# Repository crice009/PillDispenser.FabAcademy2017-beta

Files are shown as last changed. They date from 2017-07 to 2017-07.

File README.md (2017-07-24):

#Pill Dispenser (working title: Novelda)
Fab Academy2017 --beta

These files build a device that will manage pills medications for someone who needs to take them on a schedule. Ideally, this machine will dispense pills and make simple efforts to through sensors and alerts (local and internet based) to avoid too much or too little medication being taken at any time. Perhaps even with medication compliance information that could be useful for better understanding the user’s behavior. My hope was to create a valuable data stream, where there was none previously. 

To give this a more personal explanation: My grandmother recently passed of Alzheimer’s disease. My family regularly worried if she was taking her medications on schedule (as it was difficult or impossible for her to remember on her own. A device like this could manage that all for her. If everything worked perfectly, a family member could place the bottle of pills in the machine and then let it run in Grandma’s home on the kitchen counter. The machine would then dispense the pills on a schedule, but actively manage so they don’t get backlogged. An alarm would help Grandma remember when it was time to take the pills. Furthermore, an internet app could track her medication compliance, and email a family member to give Grandma a call if she seems to be getting off schedule. [This is a pie-in-the-sky dream, but the project is close to having all of those features integrated as of July 2017.] The working title given above could be a simplified name for a theoretical commercial device. It is also my own beloved grandmother’s name. 

<a href='https://youtu.be/coTj5rTIzWQ'>Fab Academy 2017 Final Project Presentation (YouTube video)</a>

Hopefully, this could be useful to anyone who needs such a device. I am hoping to develop this project further when I have some time (I am a high school science teacher in the Cleveland, OH, USA area). If anyone is willing to employ me to work on this project, I would totally be happy to explore that option. I feel that this sort of a device is a public good, that should be free or cheap. The service (internet backend, data streams, user accounts, and online interfaces) are something that I would like to explore as a cheap paid service that could enhance the system’s utility and provide a revenue stream from this type of device. 

This repository will house the updated version of Corey Rice’s 2017 Fab Academy final project. Significant changes have already happened since the end of the Fab Academy class. Corey Rice maintains the copyright for this creative work, and is happy to collaborate with anyone who would like to expand on the project. Many of the pieces and parts are derived from a variety of sources, each with their own open source licenses – the majority come from Neil Gershenfeld. Names of original copyright holders in derived programs were maintained.

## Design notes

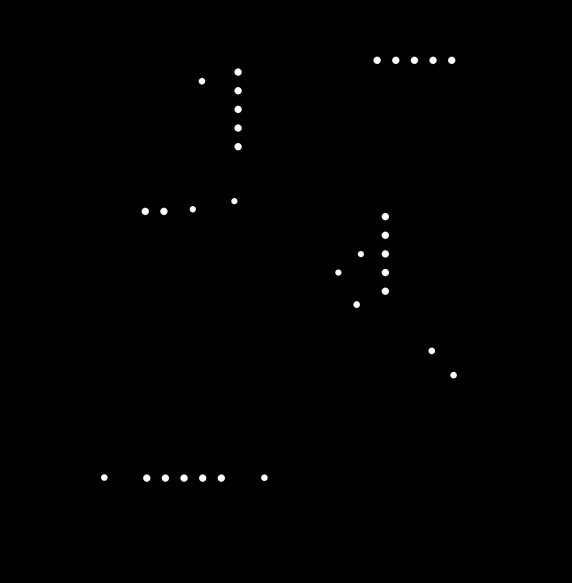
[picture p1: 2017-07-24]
hopper node controller/hopper controller/images.toolpaths/hncholes.png

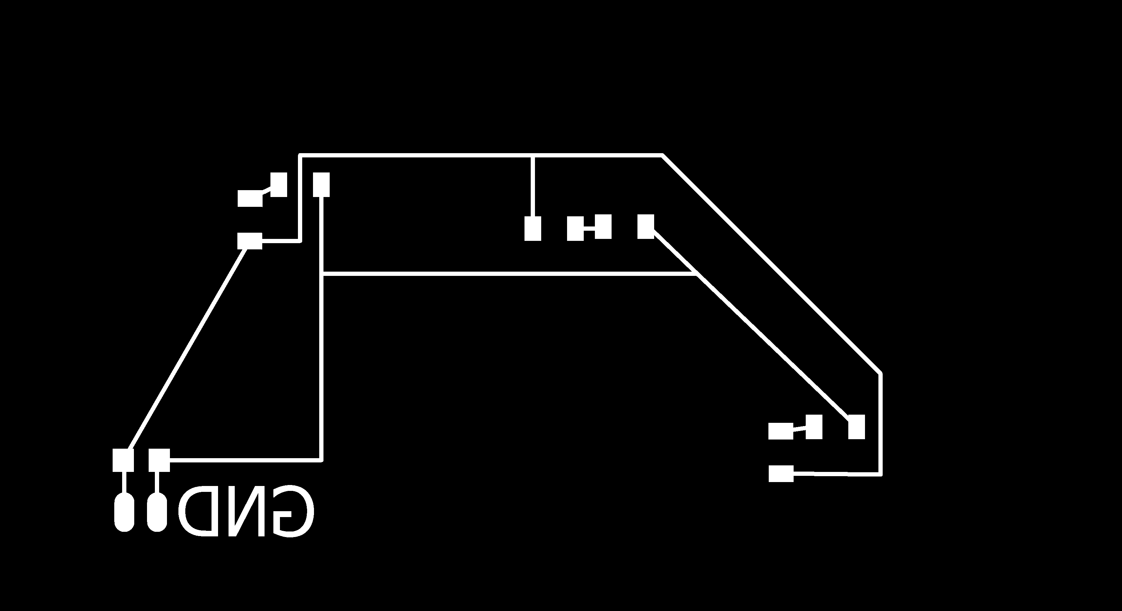
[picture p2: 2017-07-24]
hopper node controller/ir led wafer/images.toolpaths.flippedhorizontal/irlwtraces.png

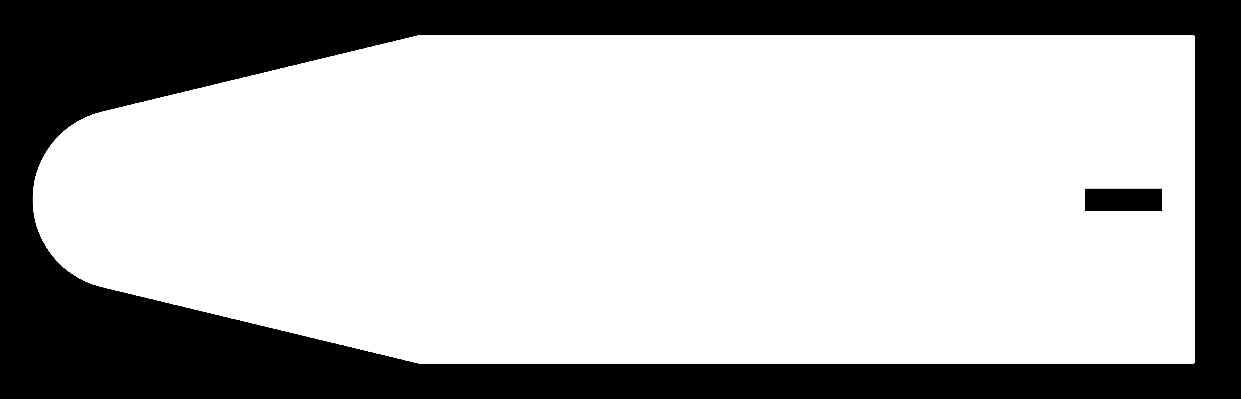
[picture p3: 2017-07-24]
main hub interface/power subpanel/images.toolpaths/pspoutline.png

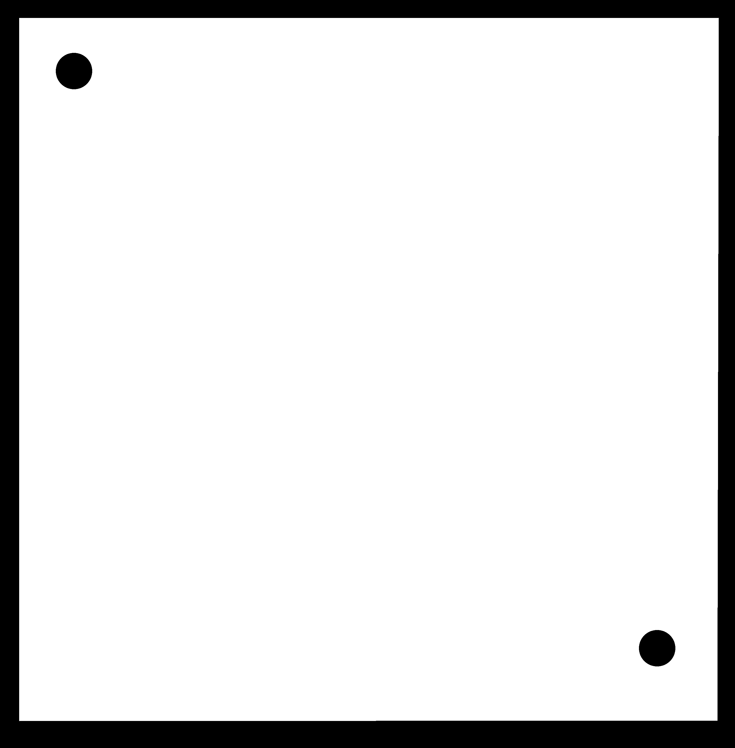
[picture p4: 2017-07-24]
hopper node controller/hopper controller/images.toolpaths/hncoutline.png

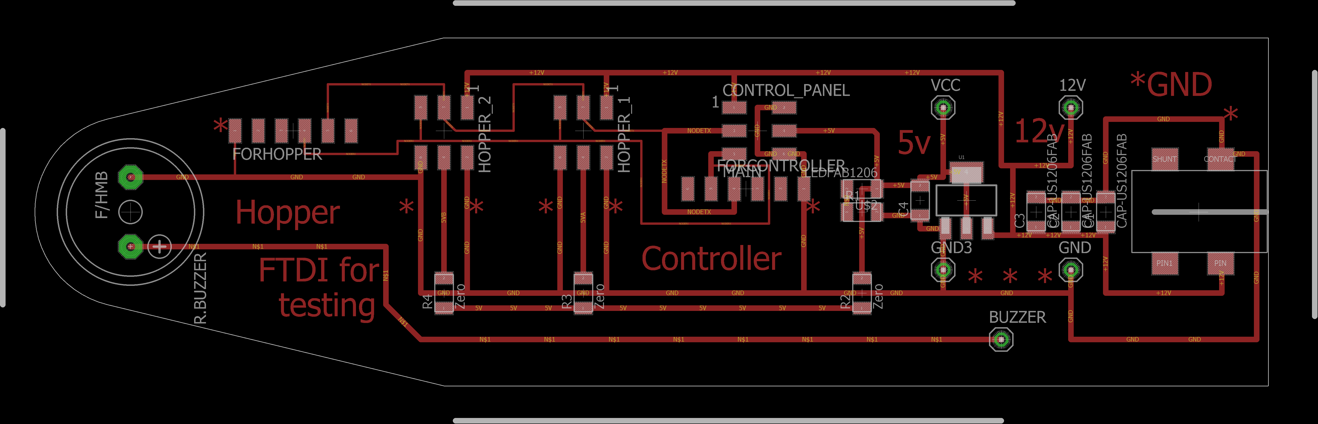
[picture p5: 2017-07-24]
main hub interface/power subpanel/images.toolpaths/powersubpanel.png

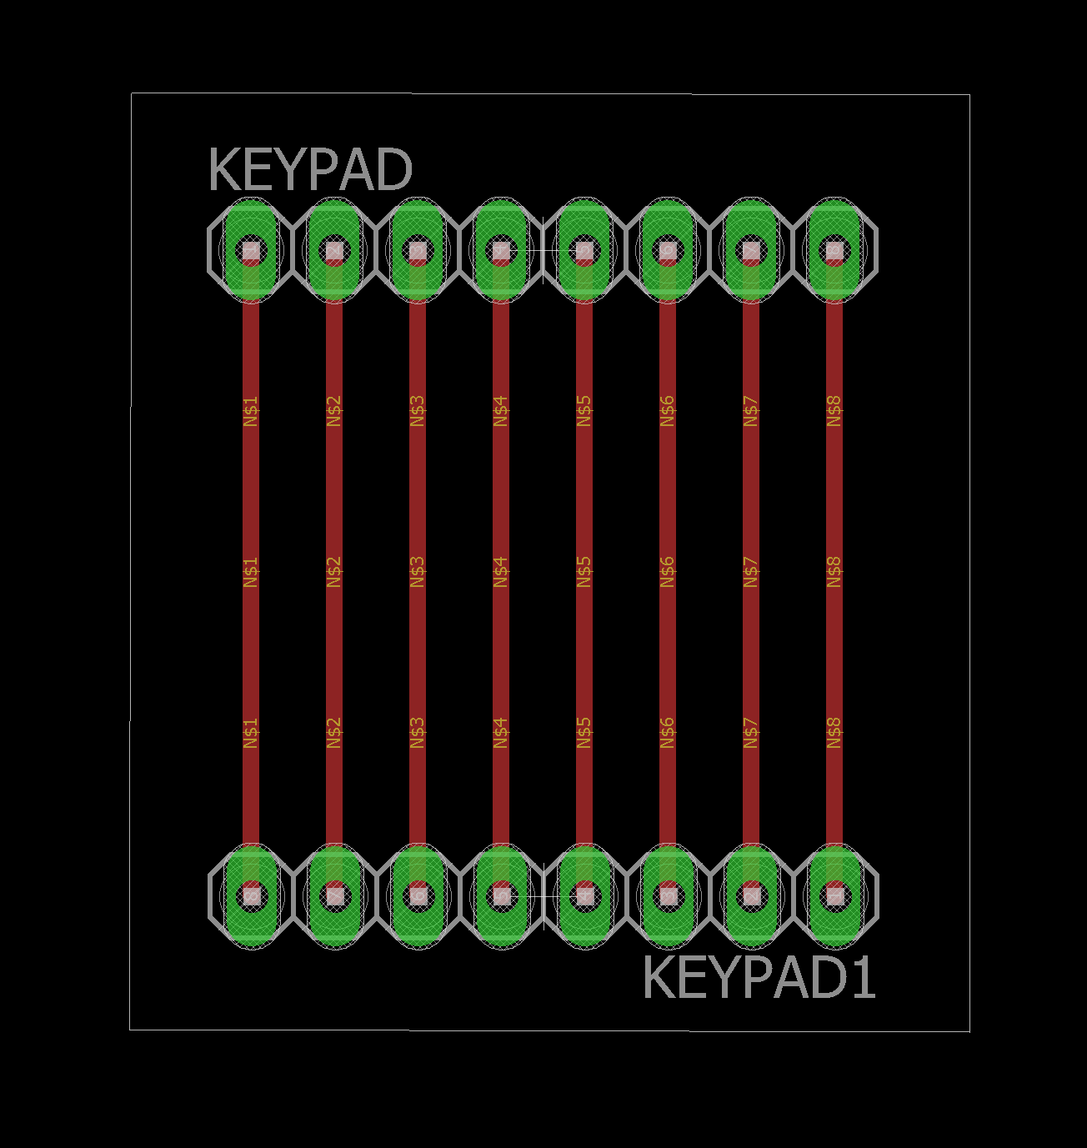
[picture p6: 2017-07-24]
main hub interface/keypad connector/images.toolpaths/keypadconnector.png

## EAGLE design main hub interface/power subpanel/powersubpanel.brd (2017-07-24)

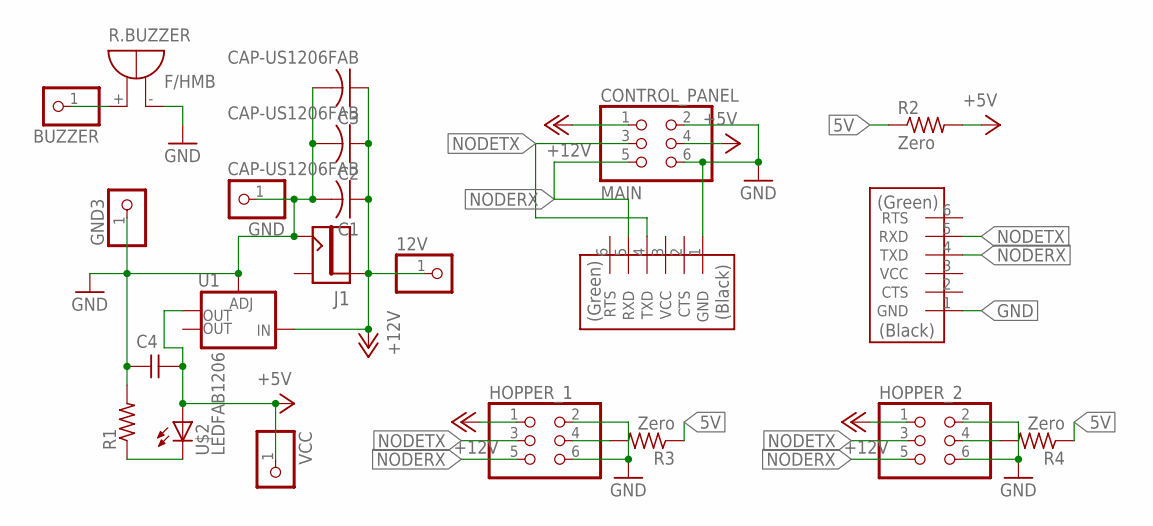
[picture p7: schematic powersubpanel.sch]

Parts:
12V: PINHD-1X1; 1X01
BUZZER: PINHD-1X1; 1X01
C1, C2, C3: CAP-US1206FAB; C1206FAB
C4: CAP-UNPOLARIZEDFAB; C1206FAB
CONTROL_PANEL: MAIN; 2X03SMD
FORCONTROLLER: FTDI-SMD-HEADER; 1X06SMD
FORHOPPER: FTDI-SMD-HEADER; 1X06SMD
GND, GND3: PINHD-1X1; 1X01
HOPPER_1, HOPPER_2: PINHD-2X3-SMD; 2X03SMD
J1: JACK2.1MM; JACK_2.1MM
R1: RES-US1206FAB; R1206FAB
R2, R3, R4: Zero; R1206FAB
R.BUZZER: F/HMB
U1: V_REG_LM1117SOT223; SOT223
U$2: LEDFAB1206; LED1206FAB
VCC: PINHD-1X1; 1X01

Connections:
5V: R2.1, R3.1, R4.1
5VA: HOPPER_1.4, R3.2
5VB: HOPPER_2.4, R4.2
+5V: C4.2, CONTROL_PANEL.4, R2.2, U1.4 (OUT), U$2.1 (A), VCC.1
+12V: 12V.1, C1.1, C2.1, C3.1, CONTROL_PANEL.1, HOPPER_1.1, HOPPER_2.1, J1.PIN, U1.3 (IN)
GND: C1.2, C2.2, C3.2, C4.1, CONTROL_PANEL.2, CONTROL_PANEL.6, FORCONTROLLER.1 (GND), FORHOPPER.1 (GND), GND.1, GND3.1, HOPPER_1.2, HOPPER_1.6, HOPPER_2.2, HOPPER_2.6, J1.CONTACT, R1.2, R.BUZZER.-, U1.1 (ADJ)
unnamed: BUZZER.1, R.BUZZER.+
unnamed: R1.1, U$2.2 (C)
NODERX: CONTROL_PANEL.5, FORCONTROLLER.5 (RXD), FORHOPPER.4 (TXD), HOPPER_1.5, HOPPER_2.5
NODETX: CONTROL_PANEL.3, FORCONTROLLER.4 (TXD), FORHOPPER.5 (RXD), HOPPER_1.3, HOPPER_2.3

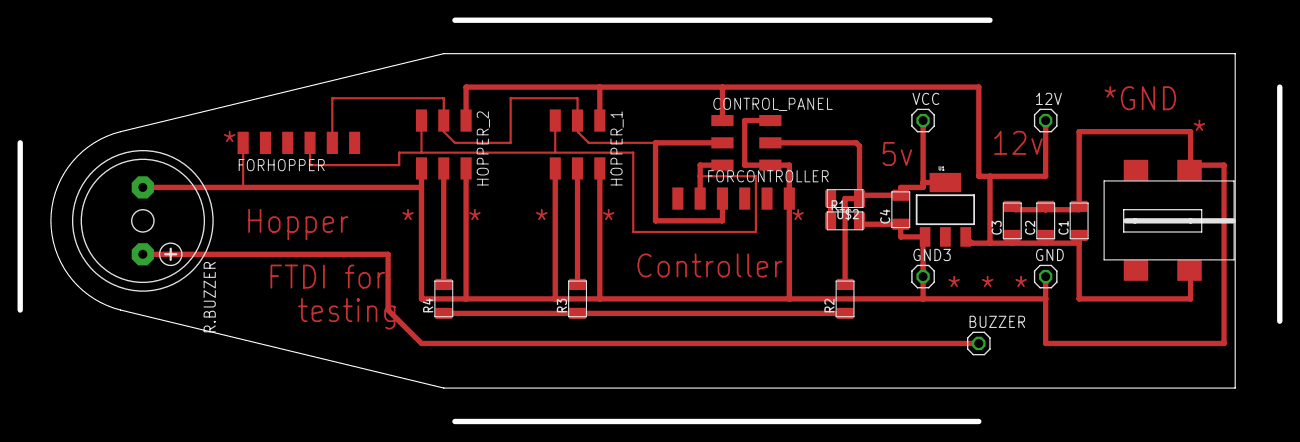
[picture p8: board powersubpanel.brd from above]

Board: 2 copper layers, 134.9 x 38.1 mm, 22 parts (0 on the bottom side), 10 nets.

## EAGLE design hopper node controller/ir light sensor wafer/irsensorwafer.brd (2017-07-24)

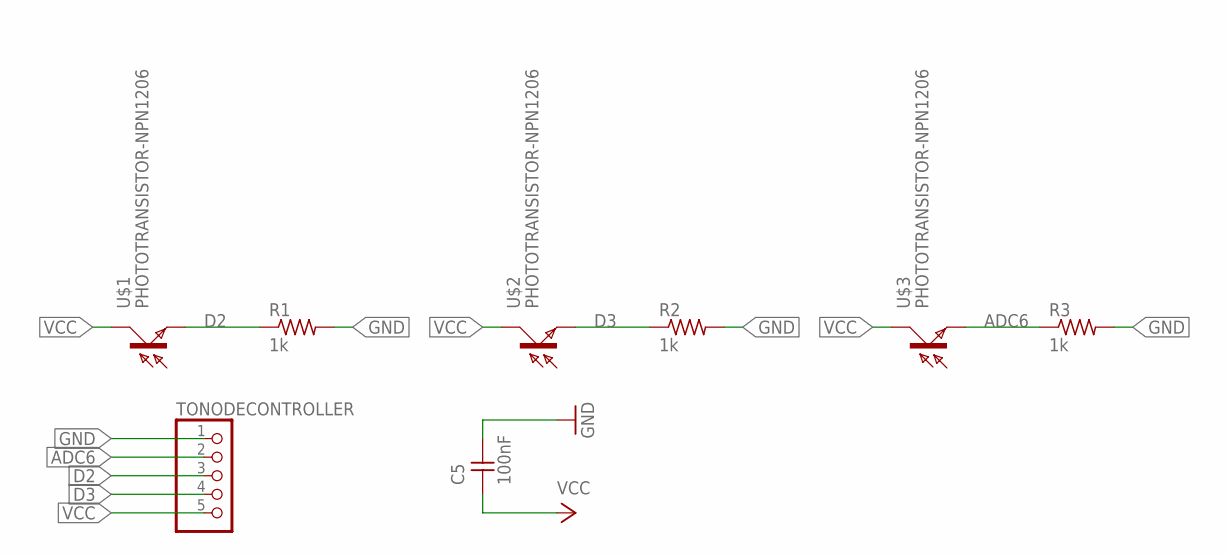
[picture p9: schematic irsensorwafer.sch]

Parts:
C5: 100nF; C1206FAB
R1, R2, R3: 1k; R1206FAB
TONODECONTROLLER: PINHD-1X5; 1X05
U$1, U$2, U$3: PHOTOTRANSISTOR-NPN1206; OP1206

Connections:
ADC6: R3.1, TONODECONTROLLER.2, U$3.EMITTER (E)
D2: R1.1, TONODECONTROLLER.3, U$1.EMITTER (E)
D3: R2.1, TONODECONTROLLER.4, U$2.EMITTER (E)
GND: C5.2, R1.2, R2.2, R3.2, TONODECONTROLLER.1
VCC: C5.1, TONODECONTROLLER.5, U$1.COLLECTOR (C), U$2.COLLECTOR (C), U$3.COLLECTOR (C)

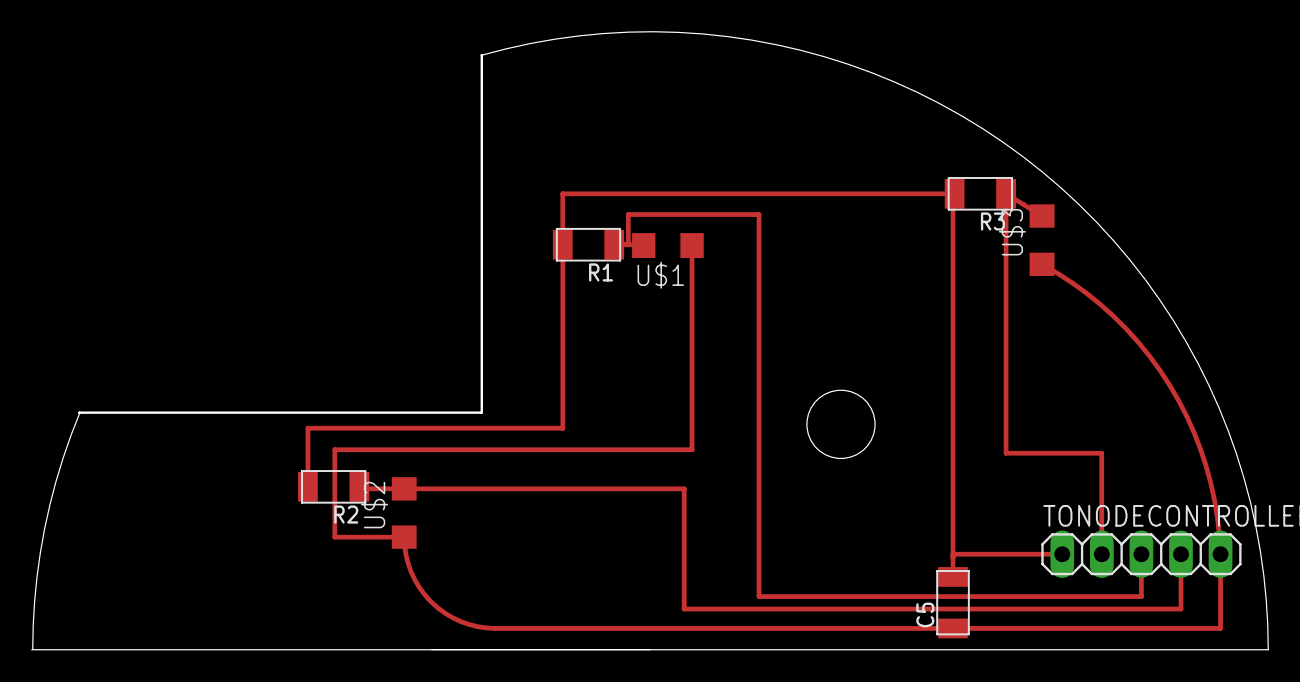
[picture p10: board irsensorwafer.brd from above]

Board: 2 copper layers, 79.4 x 39.7 mm, 8 parts (0 on the bottom side), 5 nets.

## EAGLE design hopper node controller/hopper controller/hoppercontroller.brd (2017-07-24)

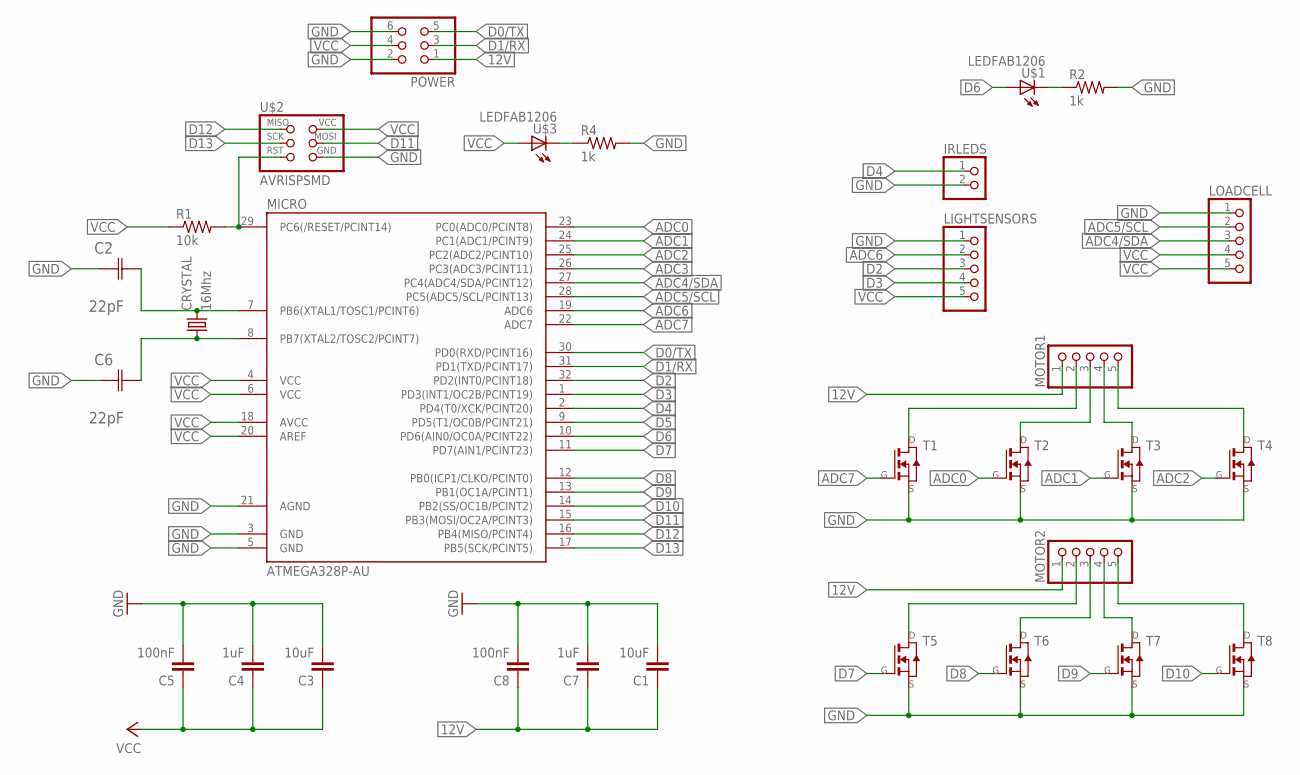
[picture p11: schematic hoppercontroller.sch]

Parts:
C1, C3: 10uF; 1206
C2, C6: 22pF; CAPC3216X178N
C4, C7: 1uF; 1206
C5, C8: 100nF; 1206
CRYSTAL: 16Mhz; CSM-7X-DU
IRLEDS: PINHD-1X2; 1X02
LIGHTSENSORS: PINHD-1X5; 1X05
LOADCELL: PINHD-1X5; 1X05
MICRO: ATMEGA328P-AU; TQFP32-08
MOTOR1, MOTOR2: PINHD-1X5; 1X05
POWER: PINHD-2X3-SMD; 2X03SMD
R1: 10k; 1206
R2, R4: 1k; R1206FAB
T1, T2, T3, T4, T5, T6, T7, T8: NMOSFETTO252; TO252
U$1, U$3: LEDFAB1206; LED1206FAB
U$2: AVRISPSMD; 2X03SMD

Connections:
12V: C1.1, C7.1, C8.1, MOTOR1.1, MOTOR2.1, POWER.1
ADC0: MICRO.23 (PC0(ADC0/PCINT8)), T2.1 (G)
ADC1: MICRO.24 (PC1(ADC1/PCINT9)), T3.1 (G)
ADC2: MICRO.25 (PC2(ADC2/PCINT10)), T4.1 (G)
ADC3: MICRO.26 (PC3(ADC3/PCINT11))
ADC4/SDA: LOADCELL.3, MICRO.27 (PC4(ADC4/SDA/PCINT12))
ADC5/SCL: LOADCELL.2, MICRO.28 (PC5(ADC5/SCL/PCINT13))
ADC6: LIGHTSENSORS.2, MICRO.19 (ADC6)
ADC7: MICRO.22 (ADC7), T1.1 (G)
D0/TX: MICRO.30 (PD0(RXD/PCINT16)), POWER.5
D1/RX: MICRO.31 (PD1(TXD/PCINT17)), POWER.3
D2: LIGHTSENSORS.3, MICRO.32 (PD2(INT0/PCINT18))
D3: LIGHTSENSORS.4, MICRO.1 (PD3(INT1/OC2B/PCINT19))
D4: IRLEDS.1, MICRO.2 (PD4(T0/XCK/PCINT20))
D5: MICRO.9 (PD5(T1/OC0B/PCINT21))
D6: MICRO.10 (PD6(AIN0/OC0A/PCINT22)), U$1.1 (A)
D7: MICRO.11 (PD7(AIN1/PCINT23)), T5.1 (G)
D8: MICRO.12 (PB0(ICP1/CLKO/PCINT0)), T6.1 (G)
D9: MICRO.13 (PB1(OC1A/PCINT1)), T7.1 (G)
D10: MICRO.14 (PB2(SS/OC1B/PCINT2)), T8.1 (G)
D11: MICRO.15 (PB3(MOSI/OC2A/PCINT3)), U$2.4 (MOSI)
D12: MICRO.16 (PB4(MISO/PCINT4)), U$2.1 (MISO)
D13: MICRO.17 (PB5(SCK/PCINT5)), U$2.3 (SCK)
GND: C1.2, C2.1 (C1), C3.2, C4.2, C5.2, C6.1 (C1), C7.2, C8.2, IRLEDS.2, LIGHTSENSORS.1, LOADCELL.1, MICRO.3 (GND), MICRO.5 (GND), MICRO.21 (AGND), POWER.2, POWER.6, R2.2, R4.2, T1.2 (S), T2.2 (S), T3.2 (S), T4.2 (S), T5.2 (S), T6.2 (S), T7.2 (S), T8.2 (S), U$2.6 (GND)
unnamed: MOTOR2.3, T6.3 (D)
unnamed: MOTOR1.3, T2.3 (D)
unnamed: MICRO.29 (PC6(/RESET/PCINT14)), R1.2, U$2.5 (RST)
unnamed: C2.2 (C2), CRYSTAL.2, MICRO.7 (PB6(XTAL1/TOSC1/PCINT6))
unnamed: MOTOR1.2, T1.3 (D)
unnamed: MOTOR1.4, T3.3 (D)
unnamed: R4.1, U$3.2 (C)
unnamed: MOTOR1.5, T4.3 (D)
unnamed: MOTOR2.2, T5.3 (D)
unnamed: MOTOR2.4, T7.3 (D)
unnamed: MOTOR2.5, T8.3 (D)
unnamed: C6.2 (C2), CRYSTAL.1, MICRO.8 (PB7(XTAL2/TOSC2/PCINT7))
unnamed: R2.1, U$1.2 (C)
VCC: C3.1, C4.1, C5.1, LIGHTSENSORS.5, LOADCELL.4, LOADCELL.5, MICRO.4 (VCC), MICRO.6 (VCC), MICRO.18 (AVCC), MICRO.20 (AREF), POWER.4, R1.1, U$2.2 (VCC), U$3.1 (A)

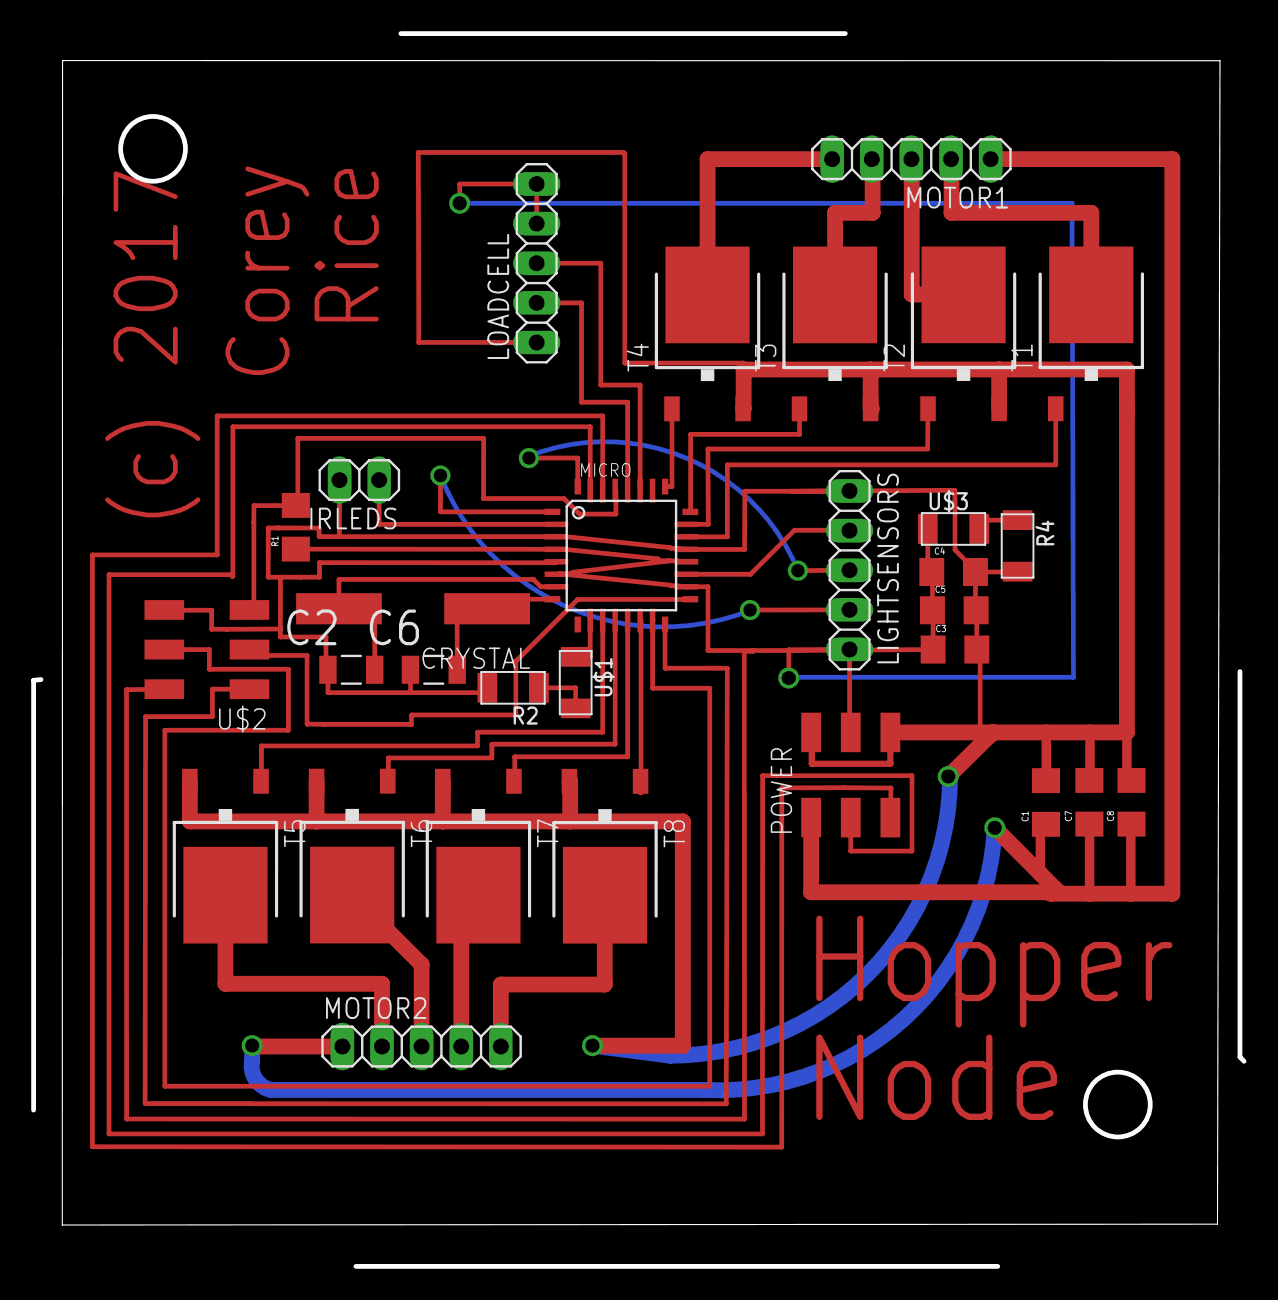
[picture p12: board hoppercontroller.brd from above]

Board: 2 copper layers, 77.6 x 79.0 mm, 30 parts (0 on the bottom side), 36 nets.

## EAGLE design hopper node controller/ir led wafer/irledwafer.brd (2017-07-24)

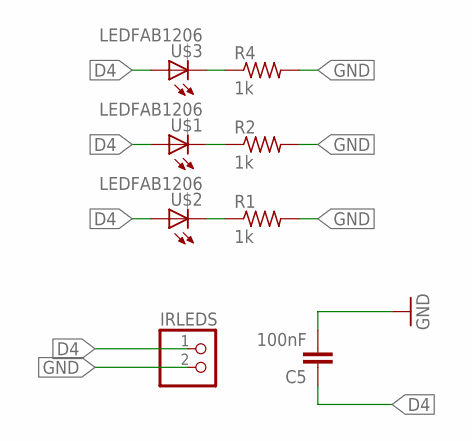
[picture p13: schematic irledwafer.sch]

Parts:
C5: 100nF; 1206
IRLEDS: PINHD-1X2; 1X02
R1, R2, R4: 1k; R1206FAB
U$1, U$2, U$3: LEDFAB1206; LED1206FAB

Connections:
D4: C5.1, IRLEDS.1, U$1.1 (A), U$2.1 (A), U$3.1 (A)
GND: C5.2, IRLEDS.2, R1.2, R2.2, R4.2
unnamed: R1.1, U$2.2 (C)
unnamed: R4.1, U$3.2 (C)
unnamed: R2.1, U$1.2 (C)

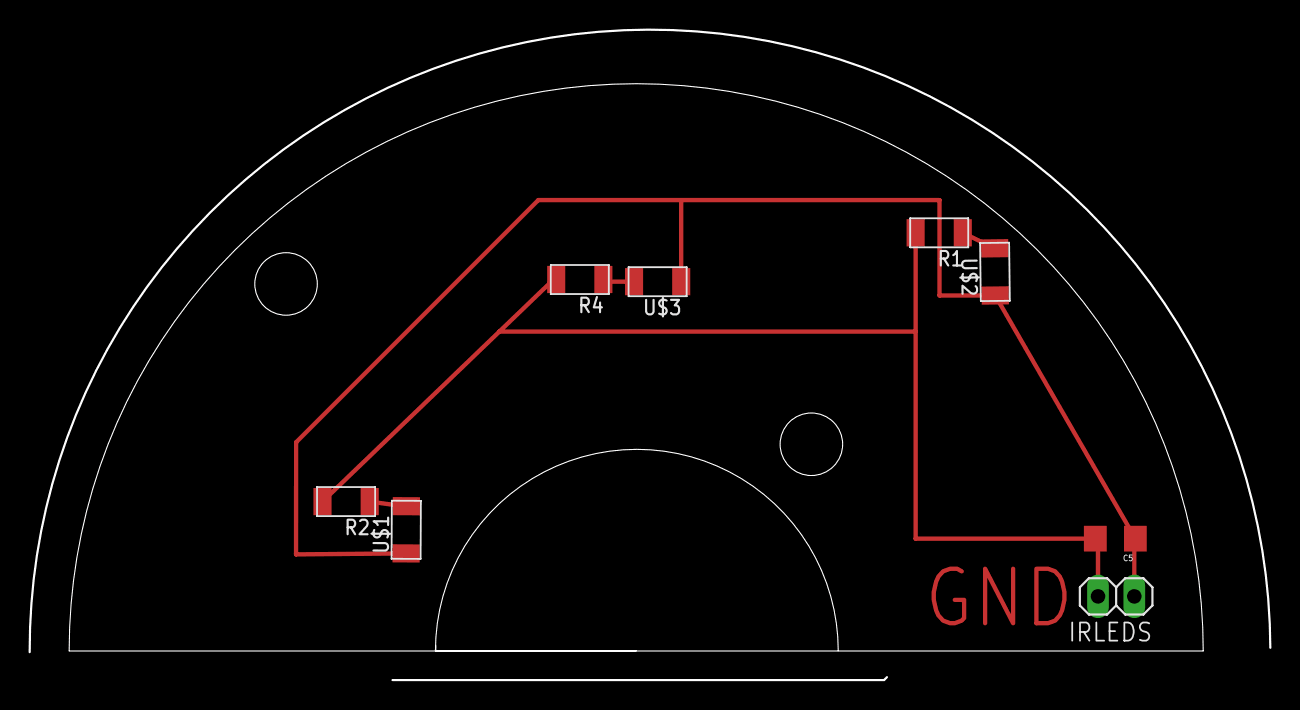
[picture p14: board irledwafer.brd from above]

Board: 2 copper layers, 79.4 x 39.7 mm, 8 parts (0 on the bottom side), 5 nets.

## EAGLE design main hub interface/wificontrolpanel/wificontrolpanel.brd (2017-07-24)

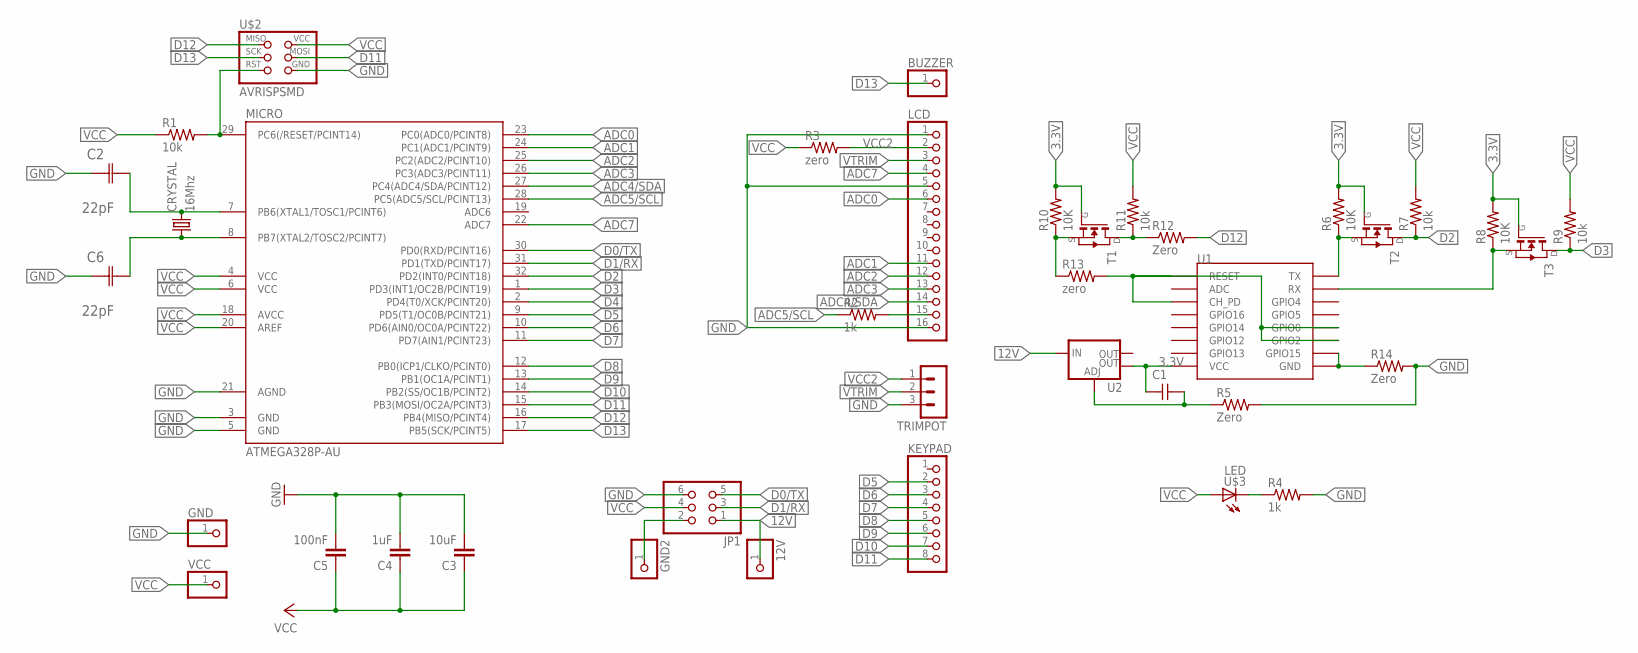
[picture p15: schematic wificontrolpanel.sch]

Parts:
12V: PINHD-1X1; 1X01
BUZZER: PINHD-1X1; 1X01
C1: CAP-UNPOLARIZEDFAB; C1206FAB
C2, C6: 22pF; CAPC3216X178N
C3: 10uF; 1206
C4: 1uF; 1206
C5: 100nF; 1206
CRYSTAL: 16Mhz; CSM-7X-DU
GND, GND2: PINHD-1X1; 1X01
JP1: PINHD-2X3-SMD; 2X03SMD
KEYPAD: PINHD-1X8; 1X08
LCD: PINHD-1X16; 1X16
MICRO: ATMEGA328P-AU; TQFP32-08
R1: 10k; 1206
R2: 1k; R1206FAB
R3, R13: zero; R1206FAB
R4: 1k; R1206
R5, R12, R14: Zero; R1206FAB
R6, R8, R10: 10K; R1206FAB
R7, R9, R11: 10k; R1206FAB
T1, T2, T3: NMOSFETSOT23; SOT-23
TRIMPOT: MA03-1
U1: ESP12SMD; ESP12-SMD
U2: V_REG_LM1117SOT223; SOT223
U$2: AVRISPSMD; 2X03SMD
U$3: LED; LED1206
VCC: PINHD-1X1; 1X01

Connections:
3.3V: C1.1, R6.2, R8.2, R10.2, T1.3 (G), T2.3 (G), T3.3 (G), U1.VCC, U2.4 (OUT)
12V: 12V.1, JP1.1, U2.3 (IN)
ADC0: LCD.6, MICRO.23 (PC0(ADC0/PCINT8))
ADC1: LCD.11, MICRO.24 (PC1(ADC1/PCINT9))
ADC2: LCD.12, MICRO.25 (PC2(ADC2/PCINT10))
ADC3: LCD.13, MICRO.26 (PC3(ADC3/PCINT11))
ADC4/SDA: LCD.14, MICRO.27 (PC4(ADC4/SDA/PCINT12))
ADC5/SCL: MICRO.28 (PC5(ADC5/SCL/PCINT13)), R2.1
ADC7: LCD.4, MICRO.22 (ADC7)
D0/TX: JP1.5, MICRO.30 (PD0(RXD/PCINT16))
D1/RX: JP1.3, MICRO.31 (PD1(TXD/PCINT17))
D2: MICRO.32 (PD2(INT0/PCINT18)), R7.1, T2.1 (D)
D3: MICRO.1 (PD3(INT1/OC2B/PCINT19)), R9.1, T3.1 (D)
D4: MICRO.2 (PD4(T0/XCK/PCINT20))
D5: KEYPAD.2, MICRO.9 (PD5(T1/OC0B/PCINT21))
D6: KEYPAD.3, MICRO.10 (PD6(AIN0/OC0A/PCINT22))
D7: KEYPAD.4, MICRO.11 (PD7(AIN1/PCINT23))
D8: KEYPAD.5, MICRO.12 (PB0(ICP1/CLKO/PCINT0))
D9: KEYPAD.6, MICRO.13 (PB1(OC1A/PCINT1))
D10: KEYPAD.7, MICRO.14 (PB2(SS/OC1B/PCINT2))
D11: KEYPAD.8, MICRO.15 (PB3(MOSI/OC2A/PCINT3)), U$2.4 (MOSI)
D12: MICRO.16 (PB4(MISO/PCINT4)), R12.2, U$2.1 (MISO)
D13: BUZZER.1, MICRO.17 (PB5(SCK/PCINT5)), U$2.3 (SCK)
GND: C2.1 (C1), C3.2, C4.2, C5.2, C6.1 (C1), GND.1, JP1.6, LCD.1, LCD.5, LCD.16, MICRO.3 (GND), MICRO.5 (GND), MICRO.21 (AGND), R4.2, R5.2, R14.2, TRIMPOT.3, U$2.6 (GND)
GND2: GND2.1, JP1.2
GND3: C1.2, R5.1, U2.1 (ADJ)
GND4: R14.1, U1.GND, U1.GPIO15
unnamed: MICRO.29 (PC6(/RESET/PCINT14)), R1.2, U$2.5 (RST)
unnamed: C2.2 (C2), CRYSTAL.2, MICRO.7 (PB6(XTAL1/TOSC1/PCINT6))
unnamed: R6.1, T2.2 (S), U1.TXD0 (TX)
unnamed: LCD.15, R2.2
unnamed: R4.1, U$3.2 (C)
unnamed: R8.1, T3.2 (S), U1.RXD0 (RX)
unnamed: R10.1, R13.1, T1.2 (S)
unnamed: R13.2, U1.CH_PD, U1.GPIO0, U1.GPIO2, U1.RESET
unnamed: R11.1, R12.1, T1.1 (D)
unnamed: C6.2 (C2), CRYSTAL.1, MICRO.8 (PB7(XTAL2/TOSC2/PCINT7))
VCC: C3.1, C4.1, C5.1, JP1.4, MICRO.4 (VCC), MICRO.6 (VCC), MICRO.18 (AVCC), MICRO.20 (AREF), R1.1, R3.1, R7.2, R9.2, R11.2, U$2.2 (VCC), U$3.1 (A), VCC.1
VCC2: LCD.2, R3.2, TRIMPOT.1
VTRIM: LCD.3, TRIMPOT.2

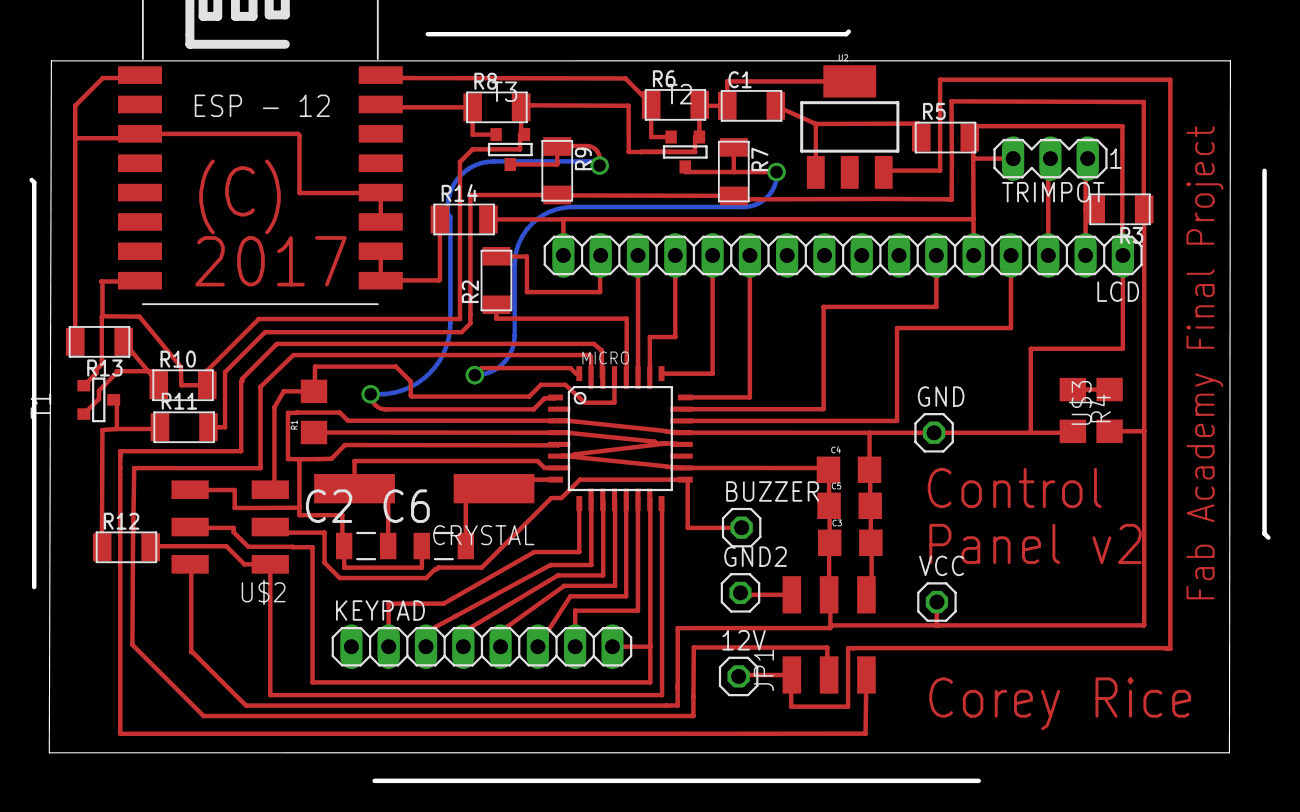
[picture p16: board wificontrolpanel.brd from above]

Board: 2 copper layers, 84.2 x 51.0 mm, 38 parts (0 on the bottom side), 39 nets.

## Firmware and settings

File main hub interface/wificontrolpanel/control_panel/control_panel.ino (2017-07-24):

//#include <pitches.h>
#include <Keypad.h>
#include <LiquidCrystal.h>
#include <SoftwareSerial.h>
#include <Adafruit_ESP8266.h>
#include <SoftwareSerial.h>

#define ROWS 4 //four rows
#define COLS 3 //three columns
char keys[ROWS][COLS] = {
  {'1','2','3'},
  {'4','5','6'},
  {'7','8','9'},
  {'*','0','#'}
};
byte rowPins[ROWS] = {5, 6, 7, 8}; //connect to the row pinouts of the keypad
byte colPins[COLS] = {9, 10, 11}; //connect to the column pinouts of the keypad

#define ESP_RX   2
#define ESP_TX   3
#define ESP_RST  12
SoftwareSerial softser(ESP_RX, ESP_TX);
Keypad keypad = Keypad( makeKeymap(keys), rowPins, colPins, ROWS, COLS );
#define backlight A5
LiquidCrystal lcd(A7, A0, A1, A2, A3, A4);

// Must declare output stream before Adafruit_ESP8266 constructor; can be
// a SoftwareSerial stream, or Serial/Serial1/etc. for UART.
Adafruit_ESP8266 wifi(&softser, &Serial, ESP_RST);
// Must call begin() on the stream(s) before using Adafruit_ESP8266 object.

#define ESP_SSID "SSIDNAME" // Your network name here
#define ESP_PASS "PASSWORD" // Your network password here

#define HOST     "www.adafruit.com"     // Host to contact
#define PAGE     "/testwifi/index.html" // Web page to request
#define PORT     80                     // 80 = HTTP default port

#define LED_PIN  A5

void setup() {
  // hardware serial connection to hopper
  Serial.begin(9600);
  /*
  while (!Serial) {
    ; // wait for serial port to connect. Needed for native USB port only
  }
  */
  pinMode(backlight, OUTPUT);
  digitalWrite(backlight,HIGH);

  // set up the LCD's number of columns and rows:
  lcd.begin(20, 4);
  // Print a message to the LCD.
  lcd.print("hello, world!");
/*
  //==================================ESP8266 setup===================
  char buffer[50];

  // Flash LED on power-up
  pinMode(LED_PIN, OUTPUT);
  for(uint8_t i=0; i<3; i++) {
    digitalWrite(13, HIGH); delay(50);
    digitalWrite(13, LOW);  delay(100);
  }

  // This might work with other firmware versions (no guarantees)
  // by providing a string to ID the tail end of the boot message:
  
  // comment/replace this if you are using something other than v 0.9.2.4!
  wifi.setBootMarker(F("Version:0.9.2.4]\r\n\r\nready"));

  softser.begin(9600); // Soft serial connection to ESP8266
  Serial.begin(57600); while(!Serial); // UART serial debug

  Serial.println(F("Adafruit ESP8266 Demo"));

  // Test if module is ready
  Serial.print(F("Hard reset..."));
  if(!wifi.hardReset()) {
    Serial.println(F("no response from module."));
    for(;;);
  }
  Serial.println(F("OK."));

  Serial.print(F("Soft reset..."));
  if(!wifi.softReset()) {
    Serial.println(F("no response from module."));
    for(;;);
  }
  Serial.println(F("OK."));

  Serial.print(F("Checking firmware version..."));
  wifi.println(F("AT+GMR"));
  if(wifi.readLine(buffer, sizeof(buffer))) {
    Serial.println(buffer);
    wifi.find(); // Discard the 'OK' that follows
  } else {
    Serial.println(F("error"));
  }

  Serial.print(F("Connecting to WiFi..."));
  if(wifi.connectToAP(F(ESP_SSID), F(ESP_PASS))) {

    // IP addr check isn't part of library yet, but
    // we can manually request and place in a string.
    Serial.print(F("OK\nChecking IP addr..."));
    wifi.println(F("AT+CIFSR"));
    if(wifi.readLine(buffer, sizeof(buffer))) {
      Serial.println(buffer);
      wifi.find(); // Discard the 'OK' that follows

      Serial.print(F("Connecting to host..."));
      if(wifi.connectTCP(F(HOST), PORT)) {
        Serial.print(F("OK\nRequesting page..."));
        if(wifi.requestURL(F(PAGE))) {
          Serial.println("OK\nSearching for string...");
          // Search for a phrase in the open stream.
          // Must be a flash-resident string (F()).
          if(wifi.find(F("working"), true)) {
            Serial.println(F("found!"));
          } else {
            Serial.println(F("not found."));
          }
        } else { // URL request failed
          Serial.println(F("error"));
        }
        wifi.closeTCP();
      } else { // TCP connect failed
        Serial.println(F("D'oh!"));
      }
    } else { // IP addr check failed
      Serial.println(F("error"));
    }
    wifi.closeAP();
  } else { // WiFi connection failed
    Serial.println(F("FAIL"));
  }
  */
}

void loop() {
  // put your main code here, to run repeatedly:
  char key = keypad.getKey();
  if (key){
    Serial.println(key);
    lcd.setCursor(0, 2);
  }
  // set the cursor to column 0, line 1
  // (note: line 1 is the second row, since counting begins with 0):
  lcd.setCursor(0, 1);
  // print the number of seconds since reset:
  lcd.print(millis() / 1000);
}



/*
// ==================================================================
// ==================================================================
// ==================================================================
// notes in the melody:
int shavenotes[] = {
  NOTE_C4, NOTE_G3, NOTE_G3, NOTE_A3, NOTE_G3, 0, NOTE_B3, NOTE_C4
};

// note durations: 4 = quarter note, 8 = eighth note, etc.:
int shavetime[] = {
  4, 8, 8, 4, 4, 4, 4, 4
};

// ==================================================================
int alarmnotes[] ={
  NOTE_C4, NOTE_G3, NOTE_A3, 0, NOTE_C4, NOTE_G3, NOTE_A3, 0, NOTE_C4, NOTE_G3, NOTE_A3
};
int alarmtime[] = {
  4, 8, 4, 2, 4, 8, 4, 2, 4, 8, 4, 2,
};

// ==================================================================
// ==================================================================
// ==================================================================

void alert(int melody, int noteDurations) {
  // iterate over the notes of the melody:
  for (int thisNote = 0; thisNote < 8; thisNote++) {

    // to calculate the note duration, take one second
    // divided by the note type.
    //e.g. quarter note = 1000 / 4, eighth note = 1000/8, etc.
    int noteDuration = 1000 / noteDurations[thisNote];
    tone(8, melody[thisNote], noteDuration);

    // to distinguish the notes, set a minimum time between them.
    // the note's duration + 30% seems to work well:
    int pauseBetweenNotes = noteDuration * 1.30;
    delay(pauseBetweenNotes);
    // stop the tone playing:
    noTone(8);
  }
}
*/

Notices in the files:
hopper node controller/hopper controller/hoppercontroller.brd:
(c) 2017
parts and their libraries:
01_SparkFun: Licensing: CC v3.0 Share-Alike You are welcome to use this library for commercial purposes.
